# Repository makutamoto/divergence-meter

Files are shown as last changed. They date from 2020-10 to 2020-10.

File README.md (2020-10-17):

Divergence Meter
=====
PICの勉強のために作りました。
言語はMPASMです。

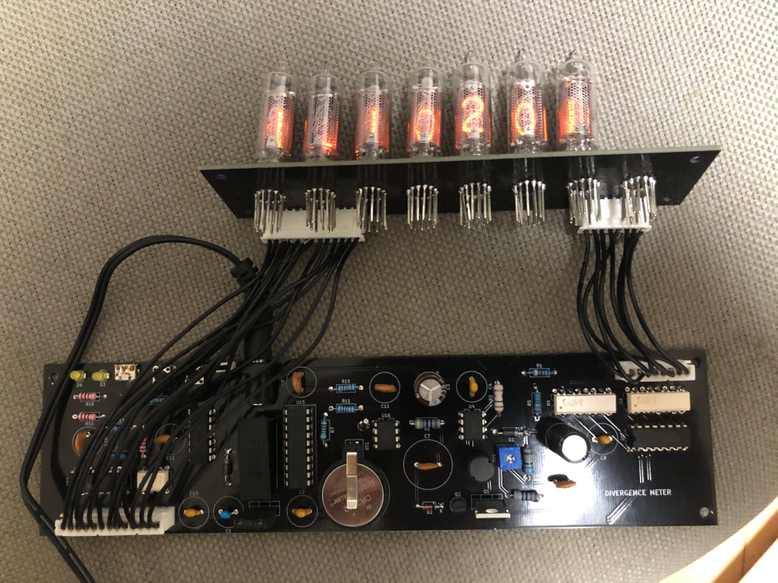
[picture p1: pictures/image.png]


[実際に動いているところ（ブレッドボード上ですが）](https://twitter.com/makutamoto/status/1317350844782632962?s=20)

divergence_meter.X/
-----
MPLABのプロジェクトです。
PICのコードが入っています。

pcb/
-----
KICADのプロジェクトです。
基盤データが入っています。

scripts/
-----
ダイバージェンスメータに様々な情報を書き込むためのスクリプトを置いています。

### add.py
世界戦変動率を追加します。

### calibrate.py
現在時刻と同期します。

### clock.py
忘れた、不明。

### preview.py
世界戦変動率をプレビューします。

### remove.py
世界戦変動率を削除します。

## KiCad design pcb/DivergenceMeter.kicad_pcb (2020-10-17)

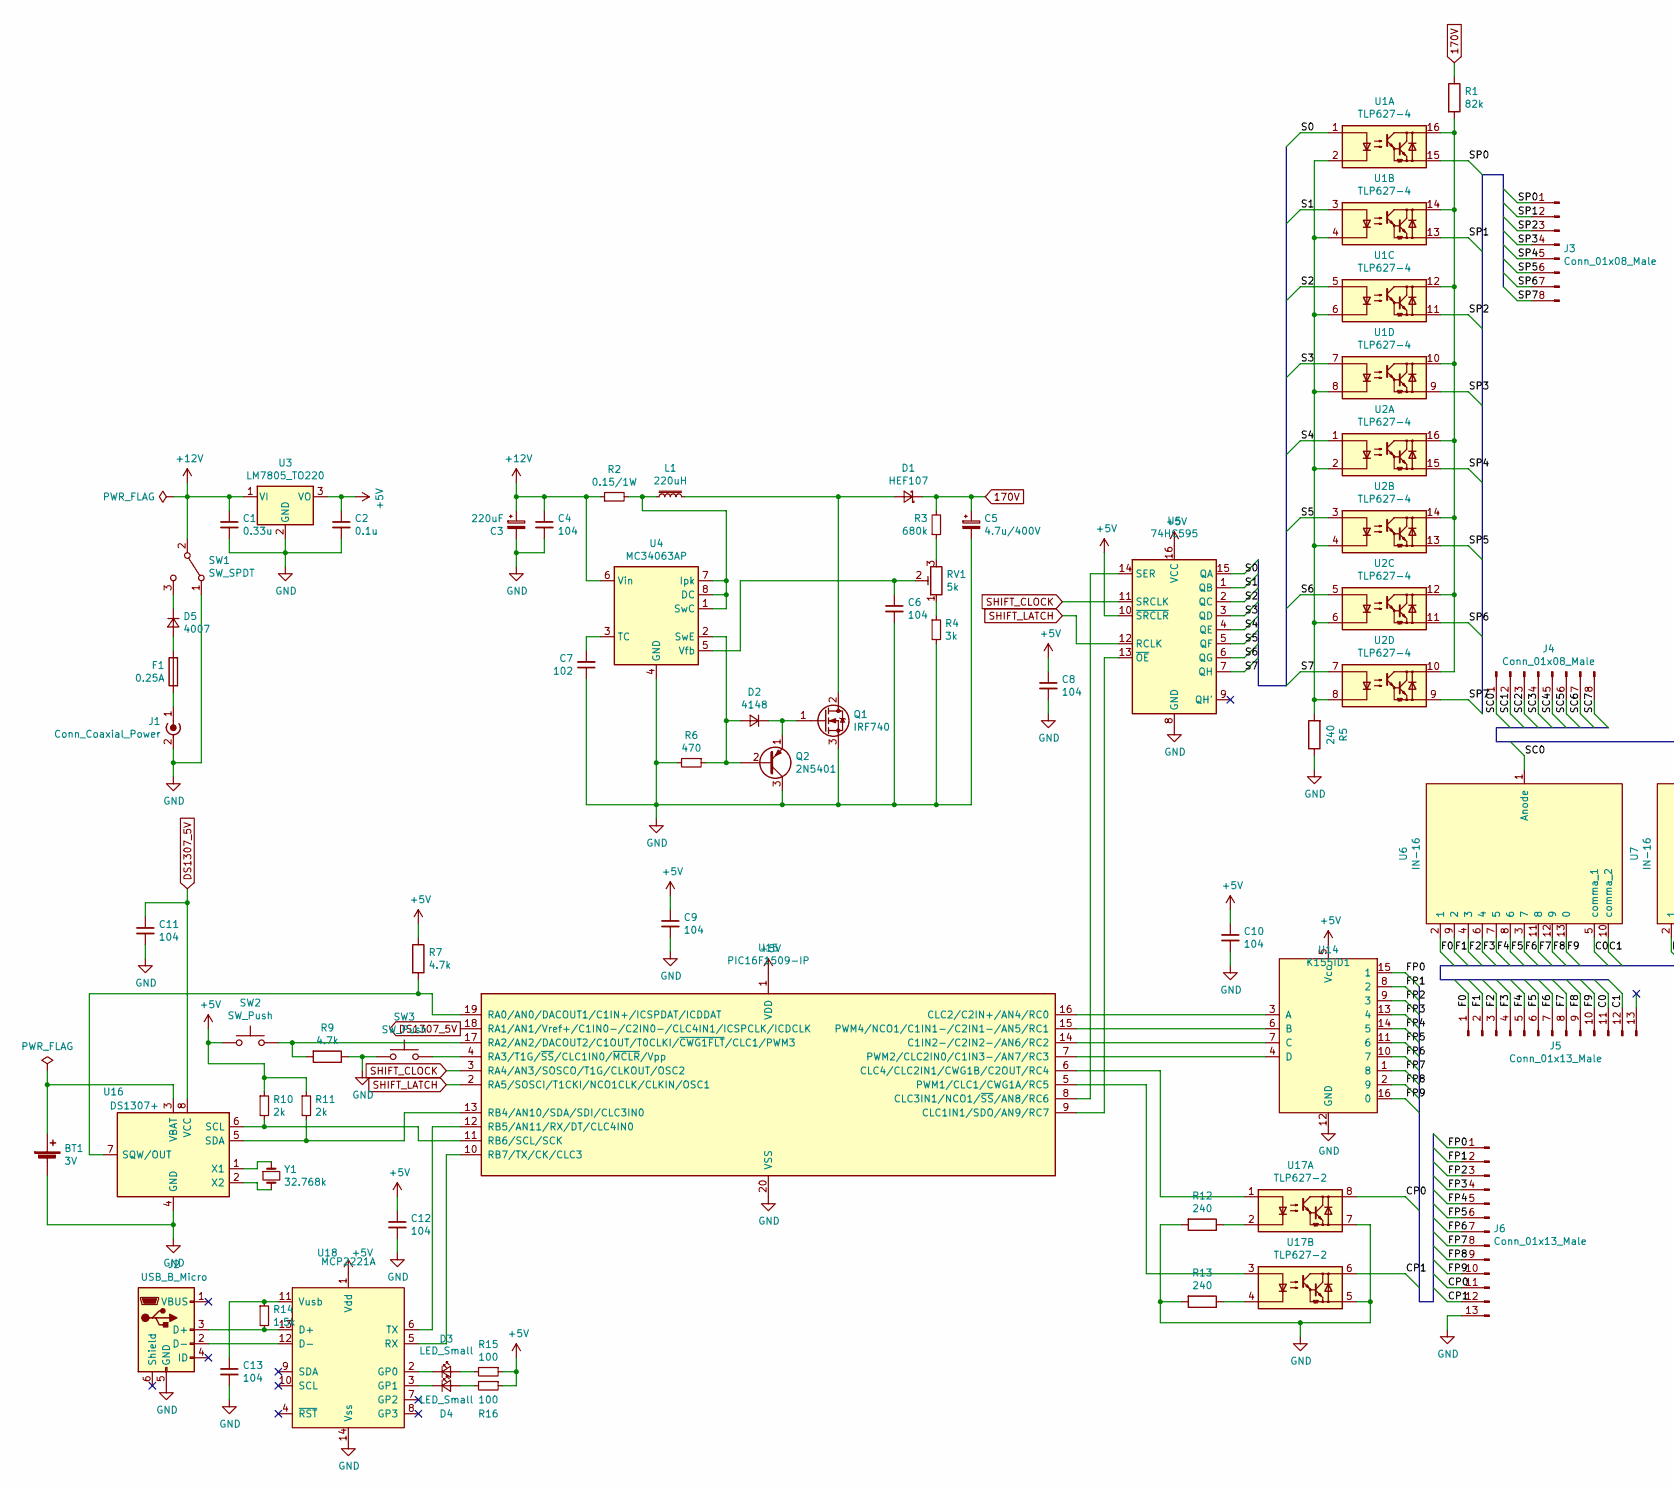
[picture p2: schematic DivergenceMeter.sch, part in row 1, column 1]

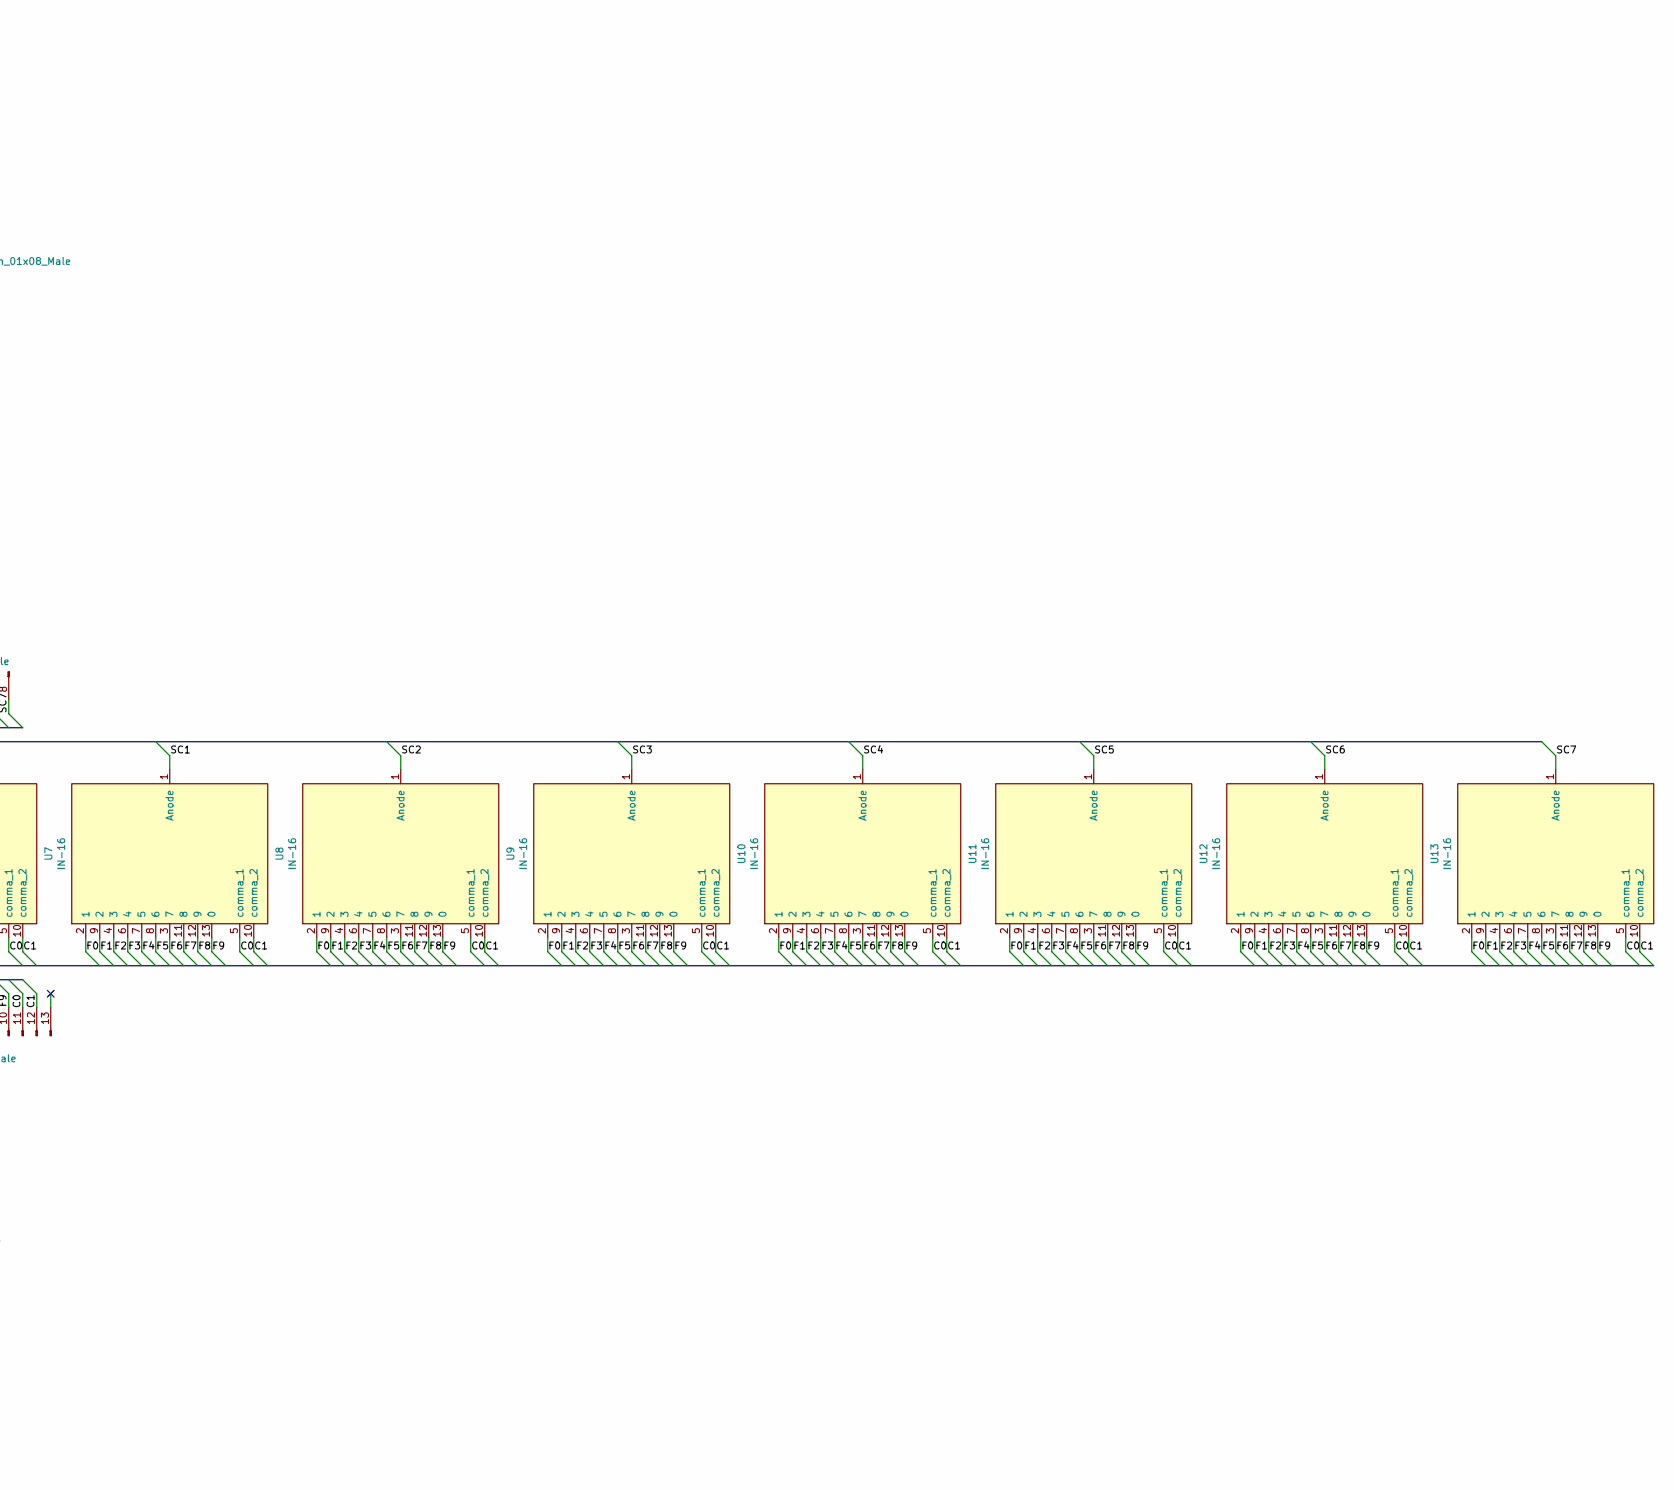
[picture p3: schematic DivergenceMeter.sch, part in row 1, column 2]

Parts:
BT1: 3V; BatteryHolder_Keystone_103_1x20mm
C1: 0.33u; C_Radial_D10.0mm_H12.5mm_P5.00mm
C2: 0.1u; C_Radial_D10.0mm_H12.5mm_P5.00mm
C3: 220uF; CP_Radial_D10.0mm_P5.00mm
C4, C6, C8, C9, C10, C11, C12, C13: 104; C_Radial_D10.0mm_H12.5mm_P5.00mm
C5: 4.7u/400V; CP_Radial_D10.0mm_P5.00mm
C7: 102; C_Radial_D16.0mm_H25.0mm_P7.50mm
D1: HEF107; D_DO-41_SOD81_P10.16mm_Horizontal
D2: 4148; D_DO-35_SOD27_P7.62mm_Horizontal
D3, D4: LED_Small; LED_D3.0mm
D5: 4007; D_DO-41_SOD81_P10.16mm_Horizontal
F1: 0.25A; Fuseholder_Cylinder-5x20mm_Schurter_0031_8201_Horizontal_Op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
J1: Conn_Coaxial_Power; DC Jack
J2: USB_B_Micro; USB_Micro-B_Molex-105017-0001
J3, J4: Conn_01x08_Male; JST_XH_B08B-XH-A_1x08_P2.50mm_Vertical
J5, J6: Conn_01x13_Male; JST_XH_B13B-XH-A_1x13_P2.50mm_Vertical
L1: 220uH; L_Radial_D6.0mm_P4.00mm
Q1: IRF740; TO-220-3_Vertical
Q2: 2N5401; TO-92_Inline
R1: 82k; R_Axial_DIN0207_L6.3mm_D2.5mm_P10.16mm_Horizontal
R2: 0.15/1W; R_Axial_DIN0207_L6.3mm_D2.5mm_P10.16mm_Horizontal
R3: 680k; R_Axial_DIN0207_L6.3mm_D2.5mm_P10.16mm_Horizontal
R4: 3k; R_Axial_DIN0207_L6.3mm_D2.5mm_P10.16mm_Horizontal
R5, R12, R13: 240; R_Axial_DIN0207_L6.3mm_D2.5mm_P10.16mm_Horizontal
R6: 470; R_Axial_DIN0207_L6.3mm_D2.5mm_P10.16mm_Horizontal
R7, R9: 4.7k; R_Axial_DIN0207_L6.3mm_D2.5mm_P10.16mm_Horizontal
R10, R11: 2k; R_Axial_DIN0207_L6.3mm_D2.5mm_P10.16mm_Horizontal
R14: 1.5k; R_Axial_DIN0207_L6.3mm_D2.5mm_P10.16mm_Horizontal
R15, R16: 100; R_Axial_DIN0207_L6.3mm_D2.5mm_P10.16mm_Horizontal
RV1: 5k; Potentiometer_Bourns_3266P_Horizontal
SW1: SW_SPDT; Slide Switch
SW2, SW3: SW_Push; SW_PUSH_6mm_H5mm
U1, U2: TLP627-4; DIP-16_W7.62mm
U3: LM7805_TO220; TO-220-3_Vertical
U4: MC34063AP; DIP-8_W7.62mm
U5: 74HC595; DIP-16_W7.62mm
U6, U7, U8, U9, U10, U11, U12, U13: IN-16
U14: K155ID1; DIP-16_W7.62mm
U15: PIC16F1509-IP; DIP-20_W7.62mm_Socket
U16: DS1307+; DIP-8_W7.62mm
U17: TLP627-2; DIP-8_W7.62mm
U18: MCP2221A; DIP-14_W7.62mm
Y1: 32.768k; Crystal_DS26_D2.0mm_L6.0mm_Vertical

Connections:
170V: C5.1, D1.1 (K), R1.1, R3.2
+5V: C2.1, C8.1, C9.1, C10.1, C12.1, R7.1, R10.1, R11.1, R15.1, R16.1, SW2.1, U3.3 (VO), U5.10 (~SRCLR), U5.16 (VCC), U14.5 (Vcc), U15.1 (VDD), U18.1 (Vdd)
+12V: C1.1, C3.1, C4.1, R2.1, SW1.2 (B), U3.1 (VI), U4.6 (Vin)
/C0: J5.11, U6.5 (comma_1), U7.5 (comma_1), U8.5 (comma_1), U9.5 (comma_1), U10.5 (comma_1), U11.5 (comma_1), U12.5 (comma_1), U13.5 (comma_1)
/C1: J5.12, U6.10 (comma_2), U7.10 (comma_2), U8.10 (comma_2), U9.10 (comma_2), U10.10 (comma_2), U11.10 (comma_2), U12.10 (comma_2), U13.10 (comma_2)
/CP0: J6.11, U17.8
/CP1: J6.12, U17.6
/F0: J5.1, U6.2 (1), U7.2 (1), U8.2 (1), U9.2 (1), U10.2 (1), U11.2 (1), U12.2 (1), U13.2 (1)
/F1: J5.2, U6.9 (2), U7.9 (2), U8.9 (2), U9.9 (2), U10.9 (2), U11.9 (2), U12.9 (2), U13.9 (2)
/F2: J5.3, U6.4 (3), U7.4 (3), U8.4 (3), U9.4 (3), U10.4 (3), U11.4 (3), U12.4 (3), U13.4 (3)
/F3: J5.4, U6.6 (4), U7.6 (4), U8.6 (4), U9.6 (4), U10.6 (4), U11.6 (4), U12.6 (4), U13.6 (4)
/F4: J5.5, U6.7 (5), U7.7 (5), U8.7 (5), U9.7 (5), U10.7 (5), U11.7 (5), U12.7 (5), U13.7 (5)
/F5: J5.6, U6.8 (6), U7.8 (6), U8.8 (6), U9.8 (6), U10.8 (6), U11.8 (6), U12.8 (6), U13.8 (6)
/F6: J5.7, U6.3 (7), U7.3 (7), U8.3 (7), U9.3 (7), U10.3 (7), U11.3 (7), U12.3 (7), U13.3 (7)
/F7: J5.8, U6.11 (8), U7.11 (8), U8.11 (8), U9.11 (8), U10.11 (8), U11.11 (8), U12.11 (8), U13.11 (8)
/F8: J5.9, U6.12 (9), U7.12 (9), U8.12 (9), U9.12 (9), U10.12 (9), U11.12 (9), U12.12 (9), U13.12 (9)
/F9: J5.10, U6.13 (0), U7.13 (0), U8.13 (0), U9.13 (0), U10.13 (0), U11.13 (0), U12.13 (0), U13.13 (0)
/FP0: J6.1, U14.15 (1)
/FP1: J6.2, U14.8 (2)
/FP2: J6.3, U14.9 (3)
/FP3: J6.4, U14.13 (4)
/FP4: J6.5, U14.14 (5)
/FP5: J6.6, U14.11 (6)
/FP6: J6.7, U14.10 (7)
/FP7: J6.8, U14.1 (8)
/FP8: J6.9, U14.2 (9)
/FP9: J6.10, U14.16 (0)
/S0: U1.1, U5.15 (QA)
/S1: U1.3, U5.1 (QB)
/S2: U1.5, U5.2 (QC)
/S3: U1.7, U5.3 (QD)
/S4: U2.1, U5.4 (QE)
/S5: U2.3, U5.5 (QF)
/S6: U2.5, U5.6 (QG)
/S7: U2.7, U5.7 (QH)
/SC0: J4.1, U6.1 (Anode)
/SC1: J4.2, U7.1 (Anode)
/SC2: J4.3, U8.1 (Anode)
/SC3: J4.4, U9.1 (Anode)
/SC4: J4.5, U10.1 (Anode)
/SC5: J4.6, U11.1 (Anode)
/SC6: J4.7, U12.1 (Anode)
/SC7: J4.8, U13.1 (Anode)
/SP0: J3.1, U1.15
/SP1: J3.2, U1.13
/SP2: J3.3, U1.11
/SP3: J3.4, U1.9
/SP4: J3.5, U2.15
/SP5: J3.6, U2.13
/SP6: J3.7, U2.11
/SP7: J3.8, U2.9
DS1307_5V: C11.1, U15.18 (RA1/AN1/Vref+/C1IN0-/C2IN0-/CLC4IN1/ICS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), U16.8 (VCC)
GND: BT1.2 (-), C1.2, C2.2, C3.2, C4.2, C5.2, C6.2, C7.1, C8.2, C9.2, C10.2, C11.2, C12.2, C13.2, J1.2 (Ext), J2.5 (GND), J6.13, Q1.3 (S), Q2.3 (C), R4.2, R5.1, R6.2, R9.1, R12.2, R13.2, SW1.1 (A), SW3.1, U3.2 (GND), U4.4 (GND), U5.8 (GND), U14.12 (GND), U15.20 (VSS), U16.4 (GND), U17.5, U17.7, U18.14 (Vss)
unnamed: BT1.1 (+), U16.3 (VBAT)
unnamed: C6.1, RV1.2, U4.5 (Vfb)
unnamed: C7.2, U4.3 (TC)
unnamed: C13.1, R14.1, U18.11 (Vusb)
unnamed: D1.2 (A), L1.2, Q1.2 (D)
unnamed: D2.1 (K), Q1.1 (G), Q2.1 (E)
unnamed: D2.2 (A), Q2.2 (B), R6.1, U4.2 (SwE)
unnamed: D3.1 (K), U18.2 (GP0)
unnamed: D3.2 (A), R15.2
unnamed: D4.1 (K), U18.3 (GP1)
unnamed: D4.2 (A), R16.2
unnamed: D5.1 (K), SW1.3 (C)
unnamed: D5.2 (A), F1.1
unnamed: F1.2, J1.1 (In)
unnamed: J2.2 (D-), U18.12 (D-)
unnamed: J2.3 (D+), R14.2, U18.13 (D+)
unnamed: L1.1, R2.2, U4.1 (SwC), U4.7 (Ipk), U4.8 (DC)
unnamed: R1.2, U1.10, U1.12, U1.14, U1.16, U2.10, U2.12, U2.14, U2.16
unnamed: R3.1, RV1.3
unnamed: R4.1, RV1.1
unnamed: R5.2, U1.2, U1.4, U1.6, U1.8, U2.2, U2.4, U2.6, U2.8
unnamed: R7.2, U15.19 (RA0/AN0/DACOUT1/C1IN+/ICSPDAT/ICDDAT), U16.7 (SQW/OUT)
unnamed: R9.2, SW2.2, U15.17 (RA2/AN2/DACOUT2/C1OUT/T0CLKI/~CWG1FLT~/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)
unnamed: R10.2, U15.11 (RB6/SCL/SCK), U16.6 (SCL)
unnamed: R11.2, U15.13 (RB4/AN10/SDA/SDI/CLC3IN0), U16.5 (SDA)
unnamed: R12.1, U17.2
unnamed: R13.1, U17.4
unnamed: SW3.2, U15.4 (RA3/T1G/~SS~/CLC1IN0/~MCLR~/Vpp)
unnamed: U14.3 (A), U15.16 (CLC2/C2IN+/AN4/RC0)
unnamed: U14.4 (D), U15.7 (PWM2/CLC2IN0/C1IN3-/AN7/RC3)
unnamed: U14.6 (B), U15.15 (PWM4/NCO1/C1IN1-/C2IN1-/AN5/RC1)
unnamed: U14.7 (C), U15.14 (C1IN2-/C2IN2-/AN6/RC2)
unnamed: U15.5 (PWM1/CLC1/CWG1A/RC5), U17.3
unnamed: U15.6 (CLC4/CLC2IN1/CWG1B/C2OUT/RC4), U17.1
unnamed: U5.14 (SER), U15.8 (CLC3IN1/NCO1/~SS~/AN8/RC6)
unnamed: U5.13 (~OE), U15.9 (CLC1IN1/SDO/AN9/RC7)
unnamed: U15.10 (RB7/TX/CK/CLC3), U18.5 (RX)
unnamed: U15.12 (RB5/AN11/RX/DT/CLC4IN0), U18.6 (TX)
unnamed: U16.1 (X1), Y1.1
unnamed: U16.2 (X2), Y1.2
SHIFT_CLOCK: U5.11 (SRCLK), U15.3 (RA4/AN3/SOSCO/T1G/CLKOUT/OSC2)
SHIFT_LATCH: U5.12 (RCLK), U15.2 (RA5/SOSCI/T1CKI/NCO1CLK/CLKIN/OSC1)

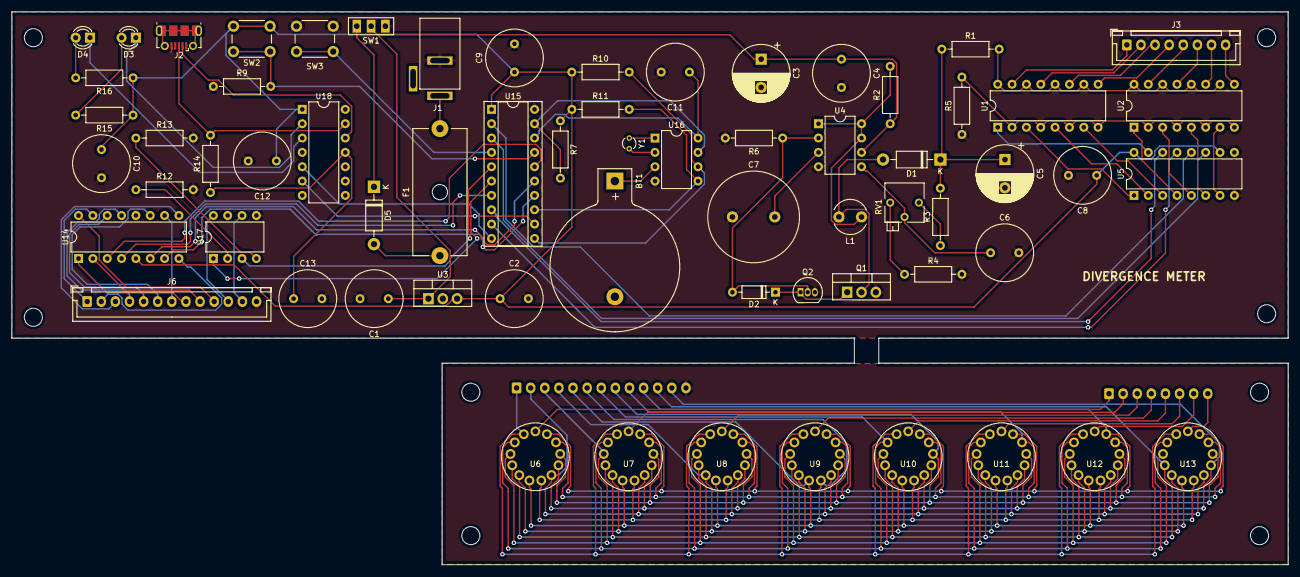
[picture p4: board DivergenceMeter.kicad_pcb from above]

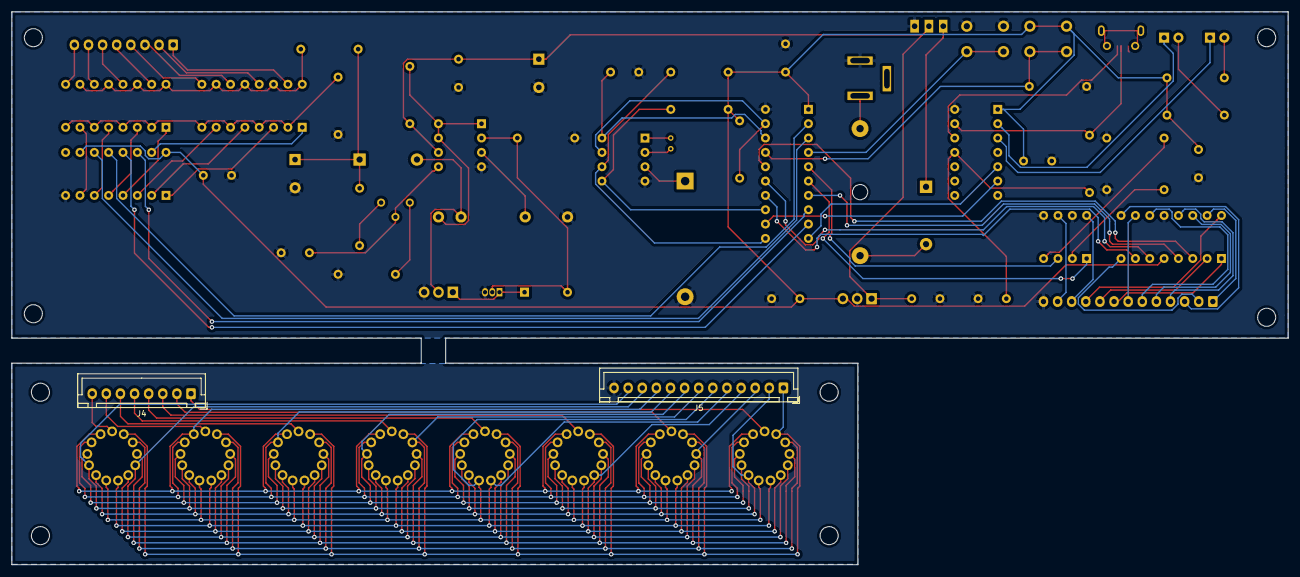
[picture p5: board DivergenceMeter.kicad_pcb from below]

Board: 2 copper layers, 226.1 x 97.9 mm, 67 parts (2 on the bottom side), 95 nets.

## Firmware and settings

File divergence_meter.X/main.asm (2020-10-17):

		LIST		    P=PIC16F1509
		#INCLUDE	    p16f1509.inc
		__CONFIG	    _CONFIG1, _FOSC_INTOSC & _CP_OFF & _BOREN_OFF & _PWRTE_ON & _WDTE_OFF & _MCLRE_ON
		__CONFIG	    _CONFIG2, _LVP_OFF
		
WREG_BACK	EQU		    H'20'
BSR_BACK	EQU		    H'21'
STATUS_BACK	EQU		    H'22'

FSR0H_BACK	EQU		    H'70'
FSR0L_BACK	EQU		    H'71'

I_FOR_INT	EQU		    H'72'
TEMP_FOR_INT	EQU		    H'73'
		
		CBLOCK		    H'74'
				    D1
				    D2
				    D3
		ENDC

WREG_BACK_2	EQU		    H'120'
		
		CBLOCK		    H'124'
				    NIXIE_VAL_0_2
				    NIXIE_VAL_1_2
				    NIXIE_VAL_2_2
				    NIXIE_VAL_3_2
				    NIXIE_VAL_4_2
				    NIXIE_VAL_5_2
				    NIXIE_VAL_6_2
				    NIXIE_VAL_7_2
		ENDC
		
		CBLOCK		    H'12C'
				    NIXIE_S_VAL_0_2
				    NIXIE_S_VAL_1_2
				    NIXIE_S_VAL_2_2
				    NIXIE_S_VAL_3_2
				    NIXIE_S_VAL_4_2
				    NIXIE_S_VAL_5_2
				    NIXIE_S_VAL_6_2
				    NIXIE_S_VAL_7_2
		ENDC
		
		CBLOCK		    H'134'
				    SHUFFLE_I_0_2
				    SHUFFLE_I_1_2
				    SHUFFLE_I_2_2
				    SHUFFLE_I_3_2
				    SHUFFLE_I_4_2
				    SHUFFLE_I_5_2
				    SHUFFLE_I_6_2
				    SHUFFLE_I_7_2
		ENDC
		
		CBLOCK		    H'13C'
				    CLOCK_VAL_SHADOW_S_2
				    CLOCK_VAL_SHADOW_M_2
				    CLOCK_VAL_SHADOW_H_2
				    CLOCK_VAL_SHADOW_DAY_2
				    CLOCK_VAL_SHADOW_DATE_2
				    CLOCK_VAL_SHADOW_MO_2
				    CLOCK_VAL_SHADOW_Y_2
		ENDC
		
		CBLOCK		    H'143'
				    NIXIE_RECV_0_2
				    NIXIE_RECV_1_2
				    NIXIE_RECV_2_2
				    NIXIE_RECV_3_2
				    NIXIE_RECV_4_2
				    NIXIE_RECV_5_2
				    NIXIE_RECV_6_2
				    NIXIE_RECV_7_2
		ENDC
	
I_2		EQU		    H'14B'
		
NIXIE_DIGIT_2	EQU		    H'14C'
SHUFFLE_S_TEMP	EQU		    H'14D'
	
DS1307_ADDRW_2	EQU		    H'14E'
DS1307_ADDRR_2	EQU		    H'14F'
DS1307_DW_2	EQU		    H'150'

LAST_HOURS_2	EQU		    H'151'
CLOCK_TEMP_2	EQU		    H'152'
	
UPDATE_CLOCKF_2 EQU		    H'153'

RECV_TEMP_2	EQU		    H'154'
RECV_C_ADDR_2	EQU		    H'155'
RECV_C_DATA_2	EQU		    H'156'
RECV_D_ADDR_2	EQU		    H'157'
RECV_D_DATA_2	EQU		    H'158'

CLOCK_DISABLE_2	EQU		    H'159'

DVR_TIMEH_2	EQU		    H'15A'
DVR_TIMEL_2	EQU		    H'15B'

I2C_TIMEOUT_2	EQU		    H'15C'
	
DVR_ADR_2	EQU		    H'15D'
	
RECV_LOCK_2	EQU		    H'15E'
	
RESET_VEC	ORG		    H'00'
		GOTO		    START
INTERRUPT	ORG		    H'04'
		MOVWF		    WREG_BACK
		SWAPF		    BSR, W
		CLRF		    BSR
		MOVWF		    BSR_BACK
		SWAPF		    STATUS, W
		MOVWF		    STATUS_BACK
		
		MOVLB		    H'00'
		BTFSC		    PIR1, RCIF
		GOTO		    INT_UART_RECV
		
		MOVLB		    H'07'
		BTFSC		    IOCAF, 0
		GOTO		    INT_DS_CLOCK
		
		BTFSC		    IOCAF, 2
		GOTO		    INT_CHANGE_DVR
		
		GOTO		    INT_END
INT_DS_CLOCK
		BCF		    IOCAF, 0
		MOVLB		    H'00'
		BTFSC		    PORTA, 0
		GOTO		    INT_END

		MOVLB		    H'02'
		MOVFW		    CLOCK_DISABLE_2
		BTFSC		    STATUS, Z
		GOTO		    INT_DS_CLOCK_0
		INCF		    DVR_TIMEL_2, F
		BTFSC		    STATUS, Z
		INCF		    DVR_TIMEH_2, F
		MOVLW		    H'10'
		SUBWF		    DVR_TIMEL_2, W
		BTFSS		    STATUS, Z
		GOTO		    INT_END
		MOVLW		    H'0E'
		SUBWF		    DVR_TIMEH_2, W
		BTFSS		    STATUS, Z
		GOTO		    INT_END
		CLRF		    DVR_TIMEH_2
		CLRF		    DVR_TIMEL_2
		CALL		    SET_SHUFFLE_2
		GOTO		    INT_END
INT_DS_CLOCK_0
		CLRF		    DVR_TIMEH_2
		CLRF		    DVR_TIMEL_2
		
		MOVLB		    H'04'
		CLRF		    WREG
		CALL		    UPDATE_CLOCK_4
		
		GOTO		    INT_END
INT_CHANGE_DVR
		BCF		    IOCAF, 2
		MOVLB		    H'00'
		CALL		    DELAY_0.01
		BTFSS		    PORTA, 2
		GOTO		    INT_END
		
		MOVLB		    H'02'
		BTFSS		    CLOCK_DISABLE_2, 1
		GOTO		    $ + 3
		CALL		    RESTORE_CLOCK_2
		GOTO		    INT_END
		BTFSC		    CLOCK_DISABLE_2, 0
		GOTO		    $ + 3
		CLRF		    DVR_ADR_2
		BSF		    CLOCK_DISABLE_2, 0
INT_CHANGE_DVR_0
		MOVLW		    H'80'
		SUBWF		    DVR_ADR_2, W
		BTFSS		    STATUS, Z
		GOTO		    $ + 3
		CALL		    RESTORE_CLOCK_2
		GOTO		    INT_END
		
		MOVFW		    DVR_ADR_2
		MOVLB		    H'03'
		CALL		    READ_HEF_3
		
		MOVLB		    H'02'
		BTFSS		    WREG, 0
		GOTO		    $ + 4
		MOVLW		    H'20'
		ADDWF		    DVR_ADR_2, F
		GOTO		    INT_CHANGE_DVR_0
		
		CALL		    BACKUP_FSR0
		MOVLW		    HIGH NIXIE_S_VAL_0_2
		MOVWF		    FSR0H
		MOVLW		    LOW NIXIE_S_VAL_0_2
		MOVWF		    FSR0L
		MOVLW		    H'08'
		MOVWF		    I_FOR_INT
INT_CHANGE_DVR_1
		INCF		    DVR_ADR_2, F
		MOVFW		    DVR_ADR_2
		MOVLB		    H'03'
		CALL		    READ_HEF_3
		
		MOVLB		    H'02'
		MOVWF		    INDF0
		
		INCF		    FSR0L, F
		DECFSZ		    I_FOR_INT
		GOTO		    INT_CHANGE_DVR_1

		MOVLW		    H'18'
		ADDWF		    DVR_ADR_2, F
		CALL		    RESTORE_FSR0
		CALL		    SET_SHUFFLE_2
		GOTO		    INT_END
INT_UART_RECV
		BCF		    PIR1, RCIF
		
		MOVLB		    H'03'
		MOVFW		    RCREG
		
		MOVLB		    H'02'
		BTFSC		    RECV_LOCK_2, 0
		GOTO		    INT_UART_RECV_UNCLOCKED
		SUBLW		    H'FA'
		BTFSS		    STATUS, Z
		GOTO		    $ + 5
		BSF		    RECV_LOCK_2, 0
		MOVLW		    H'01'
		CALL		    PUT_BYTE_2
		GOTO		    INT_END
		
		MOVLW		    H'00'
		CALL		    PUT_BYTE_2
		GOTO		    INT_END
INT_UART_RECV_UNCLOCKED		
		BTFSS		    WREG, 7
		GOTO		    INT_UART_RECV_0
		GOTO		    INT_UART_RECV_1
INT_UART_RECV_0
		BTFSS		    WREG, 6
		GOTO		    INT_UART_RECV_0_0
		GOTO		    INT_UART_RECV_0_1
INT_UART_RECV_0_0
		BTFSS		    WREG, 5
		GOTO		    INT_UART_RECV_0_0_0_1
		GOTO		    INT_UART_RECV_0_0_1
INT_UART_RECV_0_0_0_1
		MOVWF		    RECV_TEMP_2
		MOVLW		    H'0F'
		ANDWF		    RECV_TEMP_2, W
		MOVWF		    RECV_C_ADDR_2
		MOVLW		    H'01'
		CALL		    PUT_BYTE_2
		GOTO		    INT_END
INT_UART_RECV_0_0_1
		BTFSS		    WREG, 4
		GOTO		    INT_UART_RECV_0_0_1_0
		GOTO		    INT_UART_RECV_0_0_1_1
INT_UART_RECV_0_0_1_0
		MOVWF		    RECV_TEMP_2
		MOVLW		    H'0F'
		ANDWF		    RECV_C_DATA_2, F
		ANDWF		    RECV_TEMP_2, W
		LSLF		    WREG, F
		LSLF		    WREG, F
		LSLF		    WREG, F
		LSLF		    WREG, F
		IORWF		    RECV_C_DATA_2, F
		
		MOVLW		    H'01'
		CALL		    PUT_BYTE_2
		GOTO		    INT_END
INT_UART_RECV_0_0_1_1
		MOVWF		    RECV_TEMP_2
		MOVLW		    H'F0'
		ANDWF		    RECV_C_DATA_2, F
		MOVLW		    H'0F'
		ANDWF		    RECV_TEMP_2, W
		IORWF		    RECV_C_DATA_2, F
		
		MOVFW		    FSR0H
		MOVWF		    FSR0H_BACK
		MOVFW		    FSR0L
		MOVWF		    FSR0L_BACK
		
		MOVLW		    HIGH CLOCK_VAL_SHADOW_S_2
		MOVWF		    FSR0H
		MOVLW		    LOW CLOCK_VAL_SHADOW_S_2
		MOVWF		    FSR0L
		MOVLW		    D'07'
		SUBWF		    RECV_C_ADDR_2, W
		BTFSS		    STATUS, C
		GOTO		    $ + 4
		MOVLW		    H'00'
		CALL		    PUT_BYTE_2
		GOTO		    INT_END
		
		MOVFW		    RECV_C_ADDR_2
		ADDWF		    FSR0L, F
		MOVFW		    RECV_C_DATA_2
		MOVWF		    INDF0
		
		MOVFW		    FSR0H_BACK
		MOVWF		    FSR0H
		MOVFW		    FSR0L_BACK
		MOVWF		    FSR0L
		
		MOVLW		    H'01'
		CALL		    PUT_BYTE_2
		GOTO		    INT_END
INT_UART_RECV_0_1
		BTFSS		    WREG, 5
		GOTO		    INT_UART_RECV_0_1_0
		GOTO		    INT_UART_RECV_0_1_1
INT_UART_RECV_0_1_0
		CALL		    RESTORE_CLOCK_2
		
		BCF		    RECV_LOCK_2, 0
		MOVLW		    H'0F'
		CALL		    PUT_BYTE_2
		GOTO		    INT_END
INT_UART_RECV_0_1_1
		CALL		    UPDATE_DS1307_2
		MOVLB		    H'04'
		MOVLW		    H'01'
		CALL		    UPDATE_CLOCK_4
		MOVLB		    H'02'
		
		BCF		    RECV_LOCK_2, 0
		MOVLW		    H'0F'
		CALL		    PUT_BYTE_2
		GOTO		    INT_END
INT_UART_RECV_1
		BTFSS		    WREG, 6
		GOTO		    INT_UART_RECV_1_0
		GOTO		    INT_UART_RECV_1_1
INT_UART_RECV_1_0
		BTFSS		    WREG, 5
		GOTO		    INT_UART_RECV_1_0_0
		GOTO		    INT_UART_RECV_1_0_1
INT_UART_RECV_1_0_0
		MOVWF		    RECV_TEMP_2
		MOVLW		    H'0F'
		ANDWF		    RECV_TEMP_2, W
		MOVWF		    RECV_D_ADDR_2
		MOVLW		    H'01'
		CALL		    PUT_BYTE_2
		GOTO		    INT_END
INT_UART_RECV_1_0_1
		BTFSS		    WREG, 4
		GOTO		    INT_UART_RECV_1_0_1_0
		GOTO		    INT_UART_RECV_1_0_1_1
INT_UART_RECV_1_0_1_0
		MOVWF		    RECV_TEMP_2
		MOVLW		    H'0F'
		ANDWF		    RECV_D_DATA_2, F
		ANDWF		    RECV_TEMP_2, W
		LSLF		    WREG, F
		LSLF		    WREG, F
		LSLF		    WREG, F
		LSLF		    WREG, F
		IORWF		    RECV_D_DATA_2, F
		
		MOVLW		    H'01'
		CALL		    PUT_BYTE_2
		GOTO		    INT_END
INT_UART_RECV_1_0_1_1
		MOVWF		    RECV_TEMP_2
		MOVLW		    H'F0'
		ANDWF		    RECV_D_DATA_2, F
		MOVLW		    H'0F'
		ANDWF		    RECV_TEMP_2, W
		IORWF		    RECV_D_DATA_2, F
		
		MOVLB		    H'00'
		MOVFW		    FSR0H
		MOVWF		    FSR0H_BACK
		MOVFW		    FSR0L
		MOVWF		    FSR0L_BACK
		MOVLB		    H'02'
		
		MOVLW		    HIGH NIXIE_RECV_0_2
		MOVWF		    FSR0H
		MOVLW		    LOW NIXIE_RECV_0_2
		MOVWF		    FSR0L
		MOVLW		    D'08'
		SUBWF		    RECV_D_ADDR_2, W
		BTFSS		    STATUS, C
		GOTO		    $ + 4
		MOVLW		    H'00'
		CALL		    PUT_BYTE_2
		GOTO		    INT_END
		
		MOVFW		    RECV_D_ADDR_2
		ADDWF		    FSR0L, F
		MOVFW		    RECV_D_DATA_2
		MOVWF		    INDF0
		
		MOVLB		    H'00'
		MOVFW		    FSR0H_BACK
		MOVWF		    FSR0H
		MOVFW		    FSR0L_BACK
		MOVWF		    FSR0L
		MOVLB		    H'02'
		
		MOVLW		    H'01'
		CALL		    PUT_BYTE_2
		GOTO		    INT_END
INT_UART_RECV_1_1
		BTFSS		    WREG, 5
		GOTO		    INT_UART_RECV_1_1_0
		GOTO		    INT_UART_RECV_1_1_1
INT_UART_RECV_1_1_0
		MOVFW		    NIXIE_RECV_0_2
		MOVWF		    NIXIE_S_VAL_0_2
		MOVFW		    NIXIE_RECV_1_2
		MOVWF		    NIXIE_S_VAL_1_2
		MOVFW		    NIXIE_RECV_2_2
		MOVWF		    NIXIE_S_VAL_2_2
		MOVFW		    NIXIE_RECV_3_2
		MOVWF		    NIXIE_S_VAL_3_2
		MOVFW		    NIXIE_RECV_4_2
		MOVWF		    NIXIE_S_VAL_4_2
		MOVFW		    NIXIE_RECV_5_2
		MOVWF		    NIXIE_S_VAL_5_2
		MOVFW		    NIXIE_RECV_6_2
		MOVWF		    NIXIE_S_VAL_6_2
		MOVFW		    NIXIE_RECV_7_2
		MOVWF		    NIXIE_S_VAL_7_2
		
		CALL		    SET_SHUFFLE_2
		
		BSF		    CLOCK_DISABLE_2, 1
		
		BCF		    RECV_LOCK_2, 0
		MOVLW		    H'0F'
		CALL		    PUT_BYTE_2
		GOTO		    INT_END
INT_UART_RECV_1_1_1
		BTFSS		    WREG, 4
		GOTO		    INT_UART_RECV_1_1_1_0
		GOTO		    INT_UART_RECV_1_1_1_1
INT_UART_RECV_1_1_1_0
		ANDLW		    H'0F'
		MOVWF		    I_FOR_INT
		
		SUBLW		    H'03'
		BTFSC		    STATUS, C
		GOTO		    $ + 5
		BCF		    RECV_LOCK_2, 0
		MOVLW		    H'FF'
		CALL		    PUT_BYTE_2
		GOTO		    INT_END
		
		MOVLB		    H'03'
		BCF		    PMCON1, CFGS
		MOVLW		    H'1F'
		MOVWF		    PMADRH
		MOVLW		    H'80'
		MOVWF		    PMADRL
		MOVFW		    I_FOR_INT
		BTFSC		    STATUS, Z
		GOTO		    INT_UART_RECV_1_1_1_0__1
INT_UART_RECV_1_1_1_0__0
		MOVLW		    H'20'
		ADDWF		    PMADRL, F
		DECFSZ		    I_FOR_INT
		GOTO		    INT_UART_RECV_1_1_1_0__0
INT_UART_RECV_1_1_1_0__1
		MOVFW		    PMADRL
		MOVWF		    TEMP_FOR_INT
		
		BSF		    PMCON1, FREE
		BSF		    PMCON1, WREN
		CALL		    UNCLOCK_HEF_3
		BCF		    PMCON1, WREN
		
		MOVFW		    TEMP_FOR_INT
		MOVWF		    PMADRL
		BCF		    PMCON1, FREE
		BSF		    PMCON1, LWLO
		BSF		    PMCON1, WREN
		
		CLRF		    PMDATH
		CLRF		    PMDATL
		CALL		    UNCLOCK_HEF_3
		INCF		    PMADRL, F
		
		CALL		    BACKUP_FSR0
		MOVLW		    HIGH NIXIE_RECV_0_2
		MOVWF		    FSR0H
		MOVLW		    LOW NIXIE_RECV_0_2
		MOVWF		    FSR0L
		MOVLW		    H'08'
		MOVWF		    I_FOR_INT
INT_UART_RECV_1_1_1_0__4
		MOVFW		    INDF0
		MOVWF		    PMDATL
		INCF		    FSR0L, F
		
		DECFSZ		    I_FOR_INT, F
		GOTO		    $ + 2
		GOTO		    INT_UART_RECV_1_1_1_0__5
		
		CALL		    UNCLOCK_HEF_3
		INCF		    PMADRL, F
		GOTO		    INT_UART_RECV_1_1_1_0__4
INT_UART_RECV_1_1_1_0__5
		BCF		    PMCON1, LWLO
		CALL		    UNCLOCK_HEF_3
		BCF		    PMCON1, WREN
		
		CALL		    RESTORE_FSR0
		MOVLB		    H'02'
		BCF		    RECV_LOCK_2, 0
		MOVLW		    H'0F'
		CALL		    PUT_BYTE_2
		GOTO		    INT_END
INT_UART_RECV_1_1_1_1
		ANDLW		    H'0F'
		MOVWF		    I_FOR_INT
		
		SUBLW		    H'03'
		BTFSC		    STATUS, C
		GOTO		    $ + 5
		BCF		    RECV_LOCK_2, 0
		MOVLW		    H'FF'
		CALL		    PUT_BYTE_2
		GOTO		    INT_END
		
		MOVLB		    H'03'
		BCF		    PMCON1, CFGS
		MOVLW		    H'1F'
		MOVWF		    PMADRH
		MOVLW		    H'80'
		MOVWF		    PMADRL
		MOVFW		    I_FOR_INT
		BTFSC		    STATUS, Z
		GOTO		    INT_UART_RECV_1_1_1_1__1
INT_UART_RECV_1_1_1_1__0
		MOVLW		    H'20'
		ADDWF		    PMADRL, F
		DECFSZ		    I_FOR_INT
		GOTO		    INT_UART_RECV_1_1_1_1__0
INT_UART_RECV_1_1_1_1__1
		BSF		    PMCON1, FREE
		BSF		    PMCON1, WREN
		CALL		    UNCLOCK_HEF_3
		BCF		    PMCON1, WREN
		
		MOVLB		    H'02'
		BCF		    RECV_LOCK_2, 0
		MOVLW		    H'0F'
		CALL		    PUT_BYTE_2
		GOTO		    INT_END
INT_END
		MOVLB		    H'00'
		SWAPF		    STATUS_BACK, W
		MOVWF		    STATUS
		SWAPF		    BSR_BACK, W
		MOVWF		    BSR
		SWAPF		    WREG_BACK, F
		SWAPF		    WREG_BACK, W
		RETFIE

START	
		MOVLB		    H'00'
		CLRF		    PORTA
		CLRF		    PORTB
		CLRF		    PORTC
		
		MOVLB		    H'01'
		MOVLW		    B'01101000'
		MOVWF		    OSCCON
		MOVLW		    B'00001101'
		MOVWF		    TRISA
		MOVLW		    H'F0'
		MOVWF		    TRISB
		CLRF		    TRISC
		MOVLW		    B'10000010'
		MOVWF		    OPTION_REG
		
		MOVLB		    H'02'
		CLRF		    LATA
		CLRF		    LATC
		
		CALL		    CLR_SHIFT_2
		
		MOVLW		    D'0'
		MOVWF		    NIXIE_VAL_0_2
		MOVLW		    D'1'
		MOVWF		    NIXIE_VAL_1_2
		MOVLW		    D'2'
		MOVWF		    NIXIE_VAL_2_2
		MOVLW		    D'3'
		MOVWF		    NIXIE_VAL_3_2
		MOVLW		    D'4'
		MOVWF		    NIXIE_VAL_4_2
		MOVLW		    D'5'
		MOVWF		    NIXIE_VAL_5_2
		MOVLW		    D'6'
		MOVWF		    NIXIE_VAL_6_2
		MOVLW		    D'7'
		MOVWF		    NIXIE_VAL_7_2
		
		MOVLW		    B'01010000'
		MOVWF		    NIXIE_S_VAL_1_2
		
		CLRF		    CLOCK_DISABLE_2
		
		MOVLB		    H'03'
		CLRF		    ANSELA
		CLRF		    ANSELB
		CLRF		    ANSELC
		
		MOVLW		    B'00100100'
		MOVWF		    TXSTA
		MOVLW		    D'25'
		MOVWF		    SPBRGL
		MOVLW		    B'10010000'
		MOVWF		    RCSTA
		
		MOVLB		    H'04'
		MOVLW		    B'00101000'
		MOVWF		    SSP1CON1
		CLRF		    SSP1CON2
		CLRF		    SSP1STAT
		MOVLW		    H'09'
		MOVWF		    SSP1ADD
		
		MOVLB		    H'02'
		BSF		    LATA, 1
		MOVLW		    H'00'
		MOVWF		    DS1307_ADDRR_2
		MOVWF		    DS1307_ADDRW_2
		MOVLB		    H'04'
		CALL		    READ_DS1307_4
		BTFSS		    WREG, 7
		GOTO		    $ + 3
		BCF		    WREG, 7
		CALL		    WRITE_DS1307_4
		
		MOVLB		    H'02'
		MOVLW		    H'02'
		MOVWF		    DS1307_ADDRR_2
		MOVWF		    DS1307_ADDRW_2
		MOVLB		    H'04'
		CALL		    READ_DS1307_4
		BTFSS		    WREG, 6
		GOTO		    $ + 3
		BCF		    WREG, 6
		CALL		    WRITE_DS1307_4
		
		MOVLB		    H'02'
		MOVLW		    H'07'
		MOVWF		    DS1307_ADDRW_2
		MOVLB		    H'04'
		MOVLW		    B'00010000'
		CALL		    WRITE_DS1307_4
		
		MOVLW		    H'01'
		CALL		    UPDATE_CLOCK_4
		
		MOVLB		    H'07'
		BSF		    IOCAP, 2
		BSF		    IOCAN, 0
		
		MOVLB		    H'01'
		BSF		    PIE1, RCIE
		
		MOVLB		    H'00'
		MOVLW		    B'01011111'
		MOVWF		    T2CON
		MOVLW		    D'49'
		MOVWF		    PR2
		
		MOVLW		    B'11001000'
		MOVWF		    INTCON
		
		CLRF		    TMR0
		
		BCF		    PIR1, TMR2IF
		CLRF		    TMR2
		
		BCF		    PIR1, TXIF
		
MAIN
		MOVLB		    H'00'
		BTFSC		    INTCON, TMR0IF
		GOTO		    DYNAMIC
		BTFSC		    PIR1,   TMR2IF
		GOTO		    SHUFFLE
		
		GOTO		    MAIN
DYNAMIC
		BCF		    INTCON, TMR0IF
		CLRF		    TMR0
		
		MOVLB		    H'02'
		MOVLW		    HIGH NIXIE_VAL_0_2
		MOVWF		    FSR0H
		MOVLW		    LOW NIXIE_VAL_0_2
		MOVWF		    FSR0L
		MOVFW		    NIXIE_DIGIT_2
		ADDWF		    FSR0L, F
		
		MOVLW		    HIGH NIXIE_S_VAL_0_2
		MOVWF		    FSR1H
		MOVLW		    LOW NIXIE_S_VAL_0_2
		MOVWF		    FSR1L
		MOVFW		    NIXIE_DIGIT_2
		ADDWF		    FSR1L, F
		
		BCF		    LATC, 4
		BTFSC		    INDF1, 5
		BSF		    LATC, 4
		NOP
		BCF		    LATC, 5
		BTFSC		    INDF1, 4
		BSF		    LATC, 5
		
		BTFSC		    INDF1, 7
		GOTO		    DYNAMIC_2
DYNAMIC_0
		MOVLW		    B'11110000'
		ANDWF		    LATC, F
		MOVFW		    INDF0
		BTFSC		    INDF1, 6
		MOVLW		    B'00001111'
		IORWF		    LATC, F
		
		BCF		    LATA, 5
		BSF		    LATC, 6
		BCF		    LATA, 4
		NOP
		BSF		    LATA, 4
		BCF		    LATC, 6
		
		MOVFW		    NIXIE_DIGIT_2
		BTFSC		    STATUS, Z
		GOTO		    DYNAMIC_2
DYNAMIC_1
		BCF		    LATA, 4
		NOP
		BSF		    LATA, 4
		DECFSZ		    WREG, F
		GOTO		    DYNAMIC_1
DYNAMIC_2		
		BSF		    LATA, 5
		
		INCF		    NIXIE_DIGIT_2, F
		MOVLW		    B'00001000'
		SUBWF		    NIXIE_DIGIT_2, W
		BTFSC		    STATUS, Z
		CLRF		    NIXIE_DIGIT_2
		
		CALL		    CLR_SHIFT_2
		GOTO		    MAIN
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
